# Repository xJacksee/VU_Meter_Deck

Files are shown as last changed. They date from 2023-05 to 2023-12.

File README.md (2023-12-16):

# VU_Meter_Deck
Retro audio level indicator with analog driver circuit.
\
The goal of this project is to create analog driver circuit for analog VU meter gauges. This device works with standard line level audio signals and is meant to be connected paralell to audio source and reciever (headphones or amplifier). VU Meter Deck is equipped with two sets of RCA and 1/4 inch audio jack connectors, where one set is meant to be conneced to audio source and the other to reciever as a pass-through configuration.

Front view

## Driver circuit

The driver circuit is fully analog made using TL084 quad op amps for processing (one per channel). It is meant to powered by an external 12V DC 200mA power supply. 

The circuit performs these functions:

- amplify input audio signal that arbitrarly selected value of 25mV RMS will be able to achieve 0dB on gauge's scale,
- rectify ampified signal by using op amp precision full-wave rectifier circuit,
- calculate the average of recified signal by using RC circuit,
- bufer the signal to analog gauges,
- provide input and output overvoltage protection.

View of inside circuit

## Measurments and characteristic of driver circuit

Output voltage level for 25mV RMS sinusoidal signal has been measured for different frequencies and plotted on graph below using MATLAB and Curve Fitter Toolbox. Gaussian aproximation was used to create aproximating function. For this plot, output for 1kHz sine was used as a reference value.

Driving circuit output voltage level dependace on input sine frequency

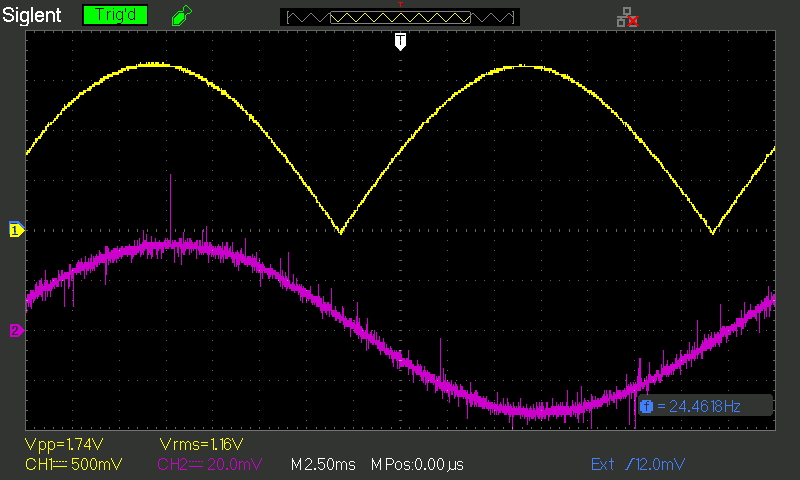
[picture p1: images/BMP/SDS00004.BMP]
Rectified 1kHz sinusoidal waveform


## Contributors
Szymon Bartosik

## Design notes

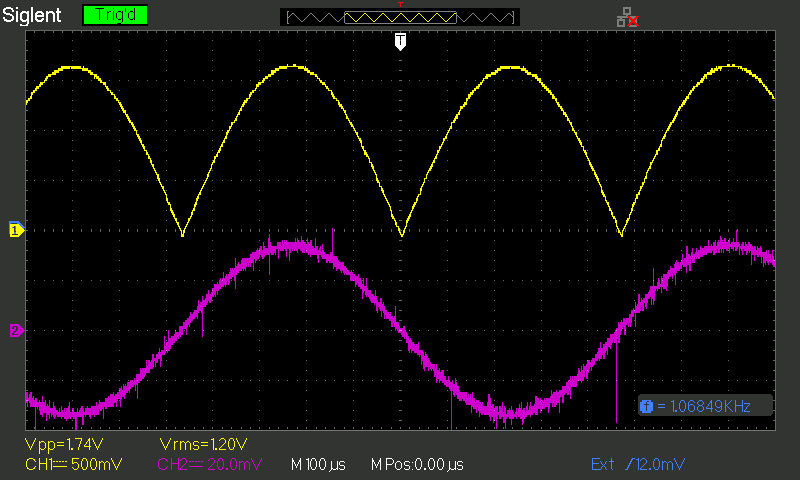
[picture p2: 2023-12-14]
images/BMP/SDS00001.BMP

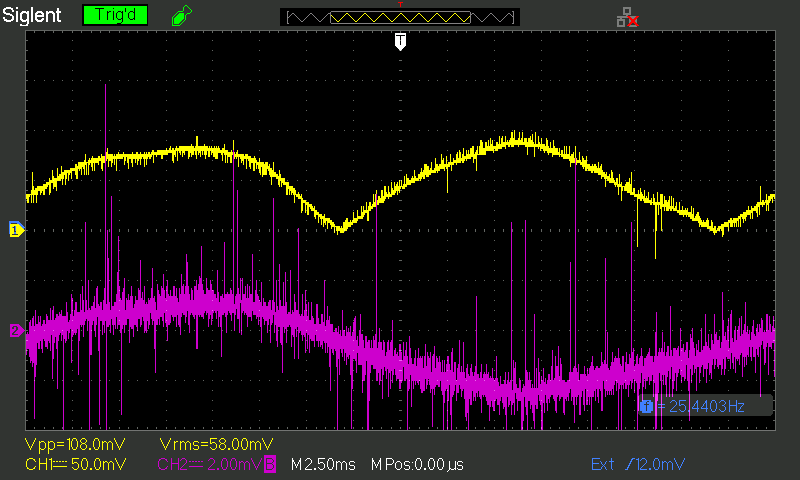
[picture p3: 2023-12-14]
images/BMP/SDS00005.BMP

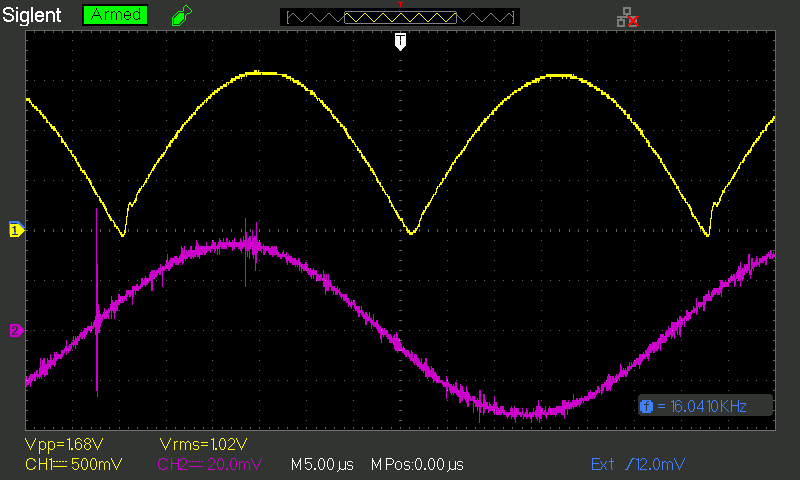
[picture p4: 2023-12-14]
images/BMP/SDS00002.BMP

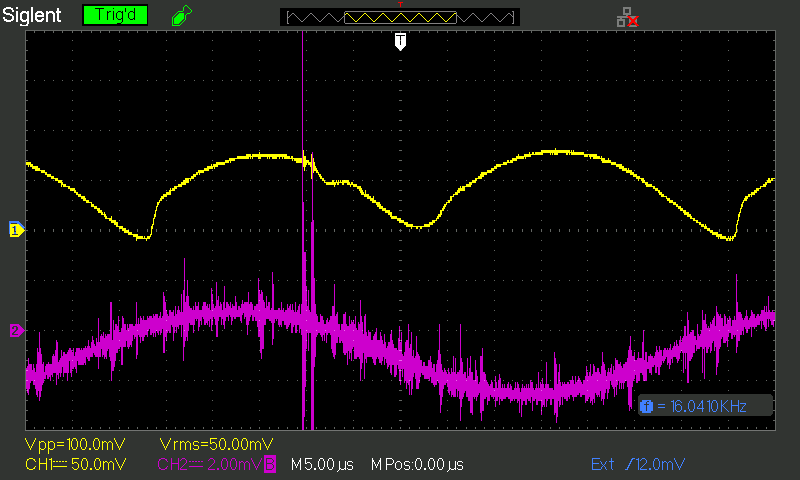
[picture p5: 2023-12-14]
images/BMP/SDS00003.BMP

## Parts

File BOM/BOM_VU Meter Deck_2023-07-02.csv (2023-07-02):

ID | Name | Designator | Footprint | Quantity | Manufacturer Part | Manufacturer | Supplier | Supplier Part
1 | 1u | C1,C4,C8,C9 | RAD-0.2 | 4 | CT40805Y105M500F3R | SR PASSIVES | TME | CCT-1U/50V
2 | 47p | C2,C5 | RAD-0.2 | 2 | CC-47/100 | SR PASSIVES | TME | CC-47/100
3 | 10u | C3,C6,C7,C10 | CAP-D5.0×F2.0 | 4 | SD1E106M05011BB | SAMWHA | TME | SD1E106M05011BB
4 | 1N4148 | D1,D4,D5,D8 | DO-35_BD2.0-L4.2-P8.20-D0.5-RD | 4 | 1N4148 | DIOTEC SEMICONDUCTOR | TME | 1N4148-DIO
5 | BAT48 | D2,D3,D6,D7 | DO-35_BD2.0-L4.2-P8.20-D0.5-RD | 4 | BAT48 | STMicroelectronics | TME | BAT48
6 | 1N4007 | D9 | DO-41_BD2.4-L4.7-P8.70-D0.9-RD | 1 | 1N4007 | DC COMPONENTS | TME | 1N4007-DC
7 | BZX55C4V3 | D10,D11,D12,D13 | DO-35_BD2.0-L4.0-P8.00-D0.5-FD | 4 | BZX55C4V3-TAP | VISHAY | TME | BZX55C4V3-TAP
8 | B3B-XH-A | J1,J3,J5 | CONN-TH_3P-P2.50_B3B-XH-A-BK-LF-SN | 3 | B3B-XH-A-BK(LF)(SN) | JST | TME | B3B-XH-A
9 | B2B-XH-A | J2,J4,J6,J7,J8 | CONN-TH_2P-P2.50_JST_B2B-XH-A-M | 5 | B2B-XH-A-M(LF)(SN)(P) | JST | TME | B2B-XH-A
10 | SCHURTER 4840.2200 | J9 |  | 1 | 4840.2200 | SCHURTER | TME | 4840.2200
11 | KEYSTONE 598 | J10,J12 |  | 2 | 598 | KEYSTONE | TME | KEYS598
12 | AMPHENOL ACJS-MVS-3 | J11,J14 |  | 2 | ACJS-MVS-3 | AMPHENOL | TME | ACJS-MVS-3
13 | KEYSTONE 580 | J13,J15 |  | 2 | 580 | KEYSTONE | TME | KEYS580
14 | AZ850-12 | K1 | AZ850 | 1 | AZ850-12 | ZETTLER | TME | AZ850-12
15 | XHP-2 | P1,P4,P6,P7,P8 |  | 5 | XHP-2 | JST | TME | XHP-2
16 | XHP-3 | P2,P3,P5 |  | 3 | XHP-3 | JST | TME | XHP-3
17 | 1k | R1,R2,R4,R7,R8,R9,R10,R12,R15,R16,R18,R20 | R_AXIAL-0.4 | 12 | CF1/4W-1K | SR PASSIVES | TME | CF1/4W-1K
18 | 47k | R3,R5,R11,R13 | R_AXIAL-0.4 | 4 | CF1/4W-47K | SR PASSIVES | TME | CF1/4W-47K
19 | 100k | R6,R14 | R_AXIAL-0.4 | 2 | CF1/4W-100K | SR PASSIVES | TME | CF1/4W-100K
20 | 10k | R17,R19,R21,R22 | R_AXIAL-0.4 | 4 | CF1/4W-10K | SR PASSIVES | TME | CF1/4W-10K
21 | 10k | RP1,RP2,RP3,RP4 | RES-ADJ-TH_3296W | 4 | T910W-10K | SR PASSIVES | TME | T910W-10K
22 | B100k | RP5,RP6 |  | 2 | R16148-1A-1-B100K | SR PASSIVES | TME | R16148-1A-1-B100K
23 | Marquardt 1801.6115 | S1 |  | 1 | 1801.6115 | Marquardt | TME | 1801.6115
24 | SD-39 | VU1,VU2 |  | 2 | SD-39
25 | TL084BCN | U1,U2 | PDIP-14 | 2 | TL084BCN | Texas Instruments | TME | TL084BCN
26 | LM358P | U3 | PDIP-8_L9.6-W6.4-P2.54-LS7.6-BL | 1 | LM358P | Texas Instruments | TME | LM358P

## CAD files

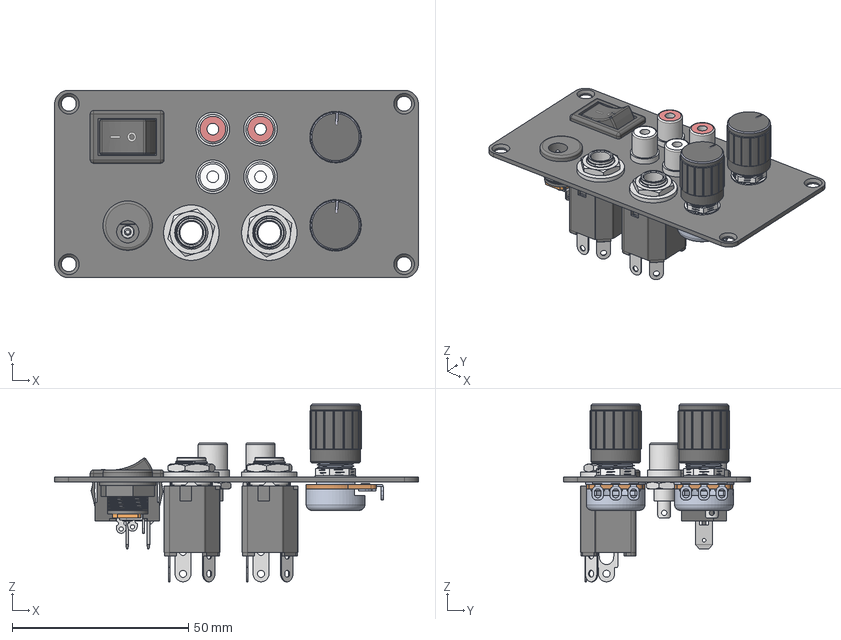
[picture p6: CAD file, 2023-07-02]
models/back_panel_assembly.stp
103.1 x 53.1 x 50.3 mm
back_panel
Housing
Rocker
Terminal x 2
RCA cinch RS 411-081_3 x 4
RCA cinch RS 411-081_0_w x 2
RCA cinch RS 411-081 x 4
RCA cinch RS 411-081_0_r x 2
RCA cinch RS 411-081_2 x 4
4840.2200-03_nut
ACJS-LNS-2S x 2
NUT x 2
Washer 2 x 2
Single_Pot x 2
Single_Pot_0 x 2
Single_Pot_1 x 2
Single_Pot_2 x 2
Single_Pot_3 x 6
Single_Pot_4 x 6
Single_Pot_5 x 2
Pot_washer x 2
Pot_nut x 2
Potentiometer knob_A15x17-PK-AB-K-I x 2

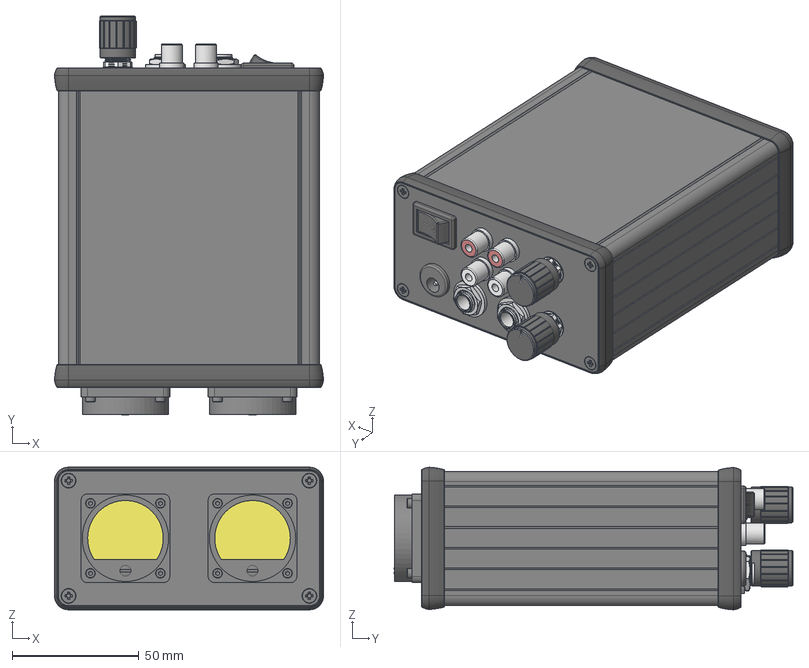
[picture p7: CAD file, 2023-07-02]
models/vu_meter_deck_assembly.stp
106.1 x 157.4 x 56.3 mm
1455N Extrusion
1455N Cover
1455 screw x 8
N1 Bezel Closed x 2
front_panel
SD-39_VU_gauge x 2
din_912-m2x0_4-10-10_9 x 8
nut_din934_m2-10 x 8
back_panel
Housing
Rocker
Terminal x 2
RCA cinch RS 411-081_3 x 4
RCA cinch RS 411-081_0_w x 2
RCA cinch RS 411-081 x 4
RCA cinch RS 411-081_0_r x 2
RCA cinch RS 411-081_2 x 4
4840.2200-03_nut
ACJS-LNS-2S x 2
NUT x 2
Washer 2 x 2
Single_Pot x 2
Single_Pot_0 x 2
Single_Pot_1 x 2
Single_Pot_2 x 2
Single_Pot_3 x 6
Single_Pot_4 x 6
Single_Pot_5 x 2
Pot_washer x 2
Pot_nut x 2
Potentiometer knob_A15x17-PK-AB-K-I x 2
board_plain

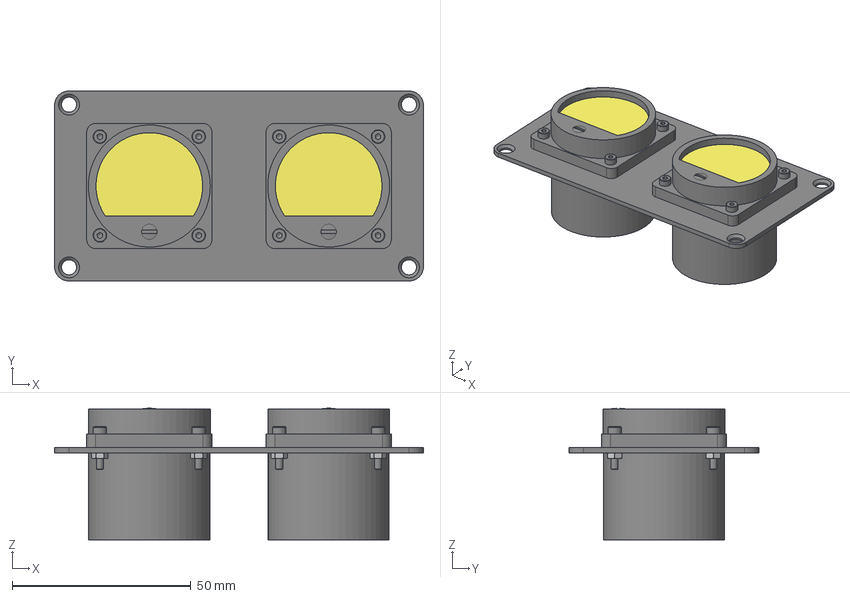
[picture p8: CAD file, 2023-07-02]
models/front_panel_assembly.stp
103.1 x 53.1 x 36.8 mm
front_panel
SD-39_VU_gauge x 2
din_912-m2x0_4-10-10_9 x 8
nut_din934_m2-10 x 8

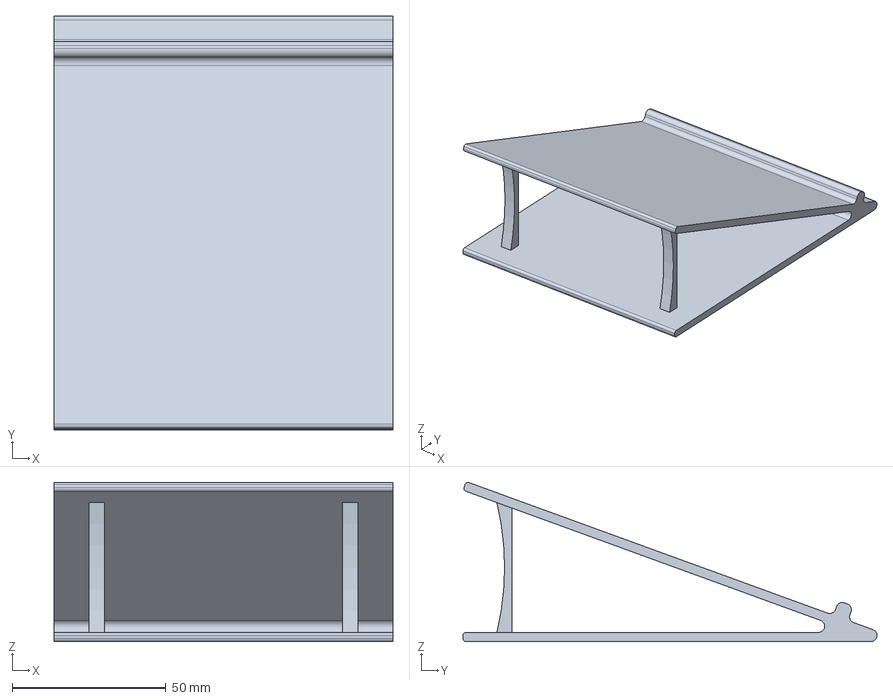
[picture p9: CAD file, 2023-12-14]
models/accessories/VU_Meter_Deck_Stand.stp
110.0 x 134.5 x 51.7 mm

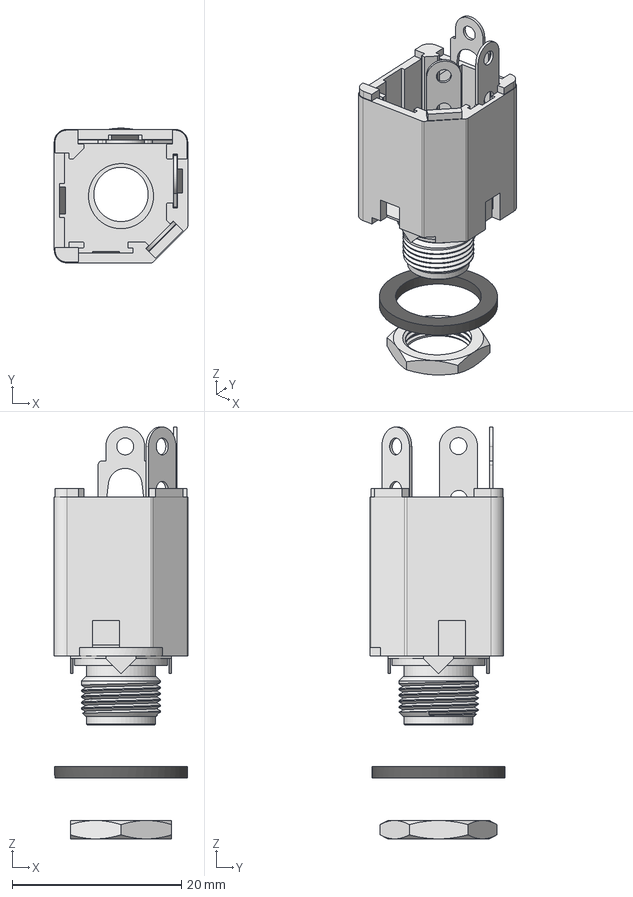
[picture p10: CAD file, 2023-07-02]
models/connectors/audio_jack/ACJS-MVS-3.stp
15.8 x 15.9 x 48.7 mm
ACJS-LNS-2S
Washer 2
NUT

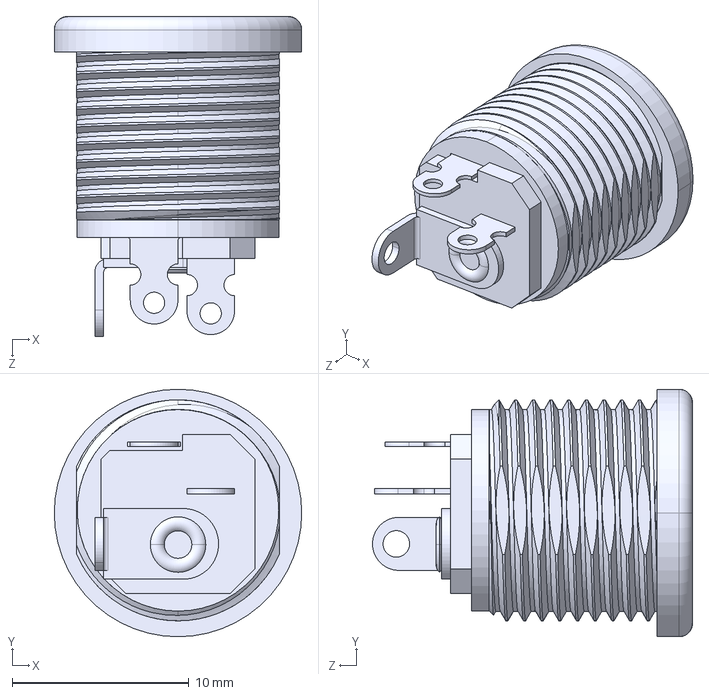
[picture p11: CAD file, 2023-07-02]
models/connectors/dc_jack/4840.2200-03.STEP
14.0 x 14.0 x 18.1 mm

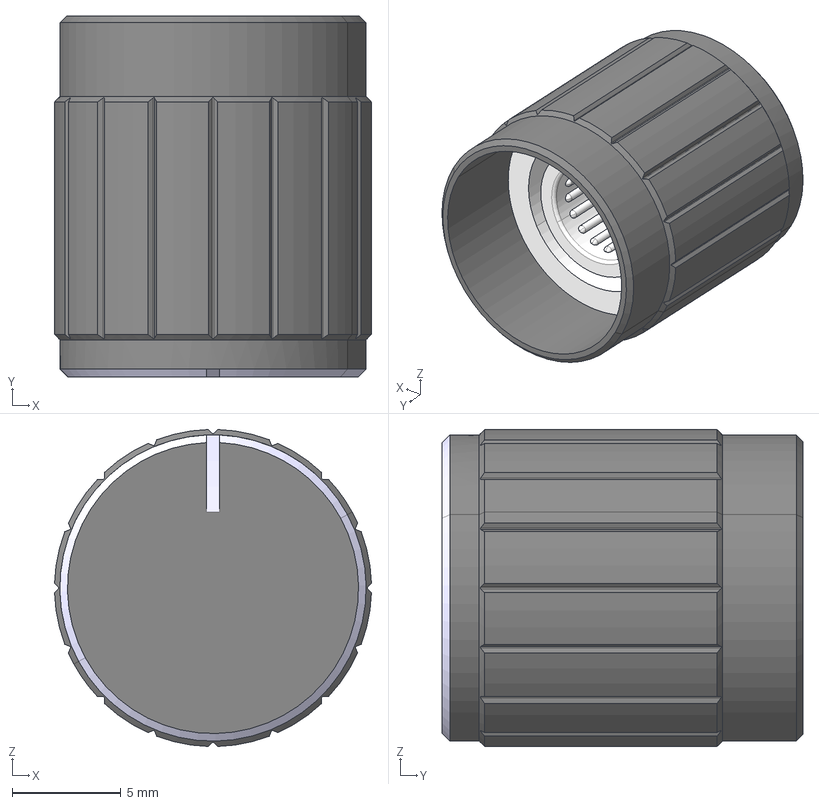
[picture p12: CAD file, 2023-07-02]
models/knob/Potentiometer knob_A15x17-PK-AB-K-I.stp
14.6 x 16.6 x 14.6 mm

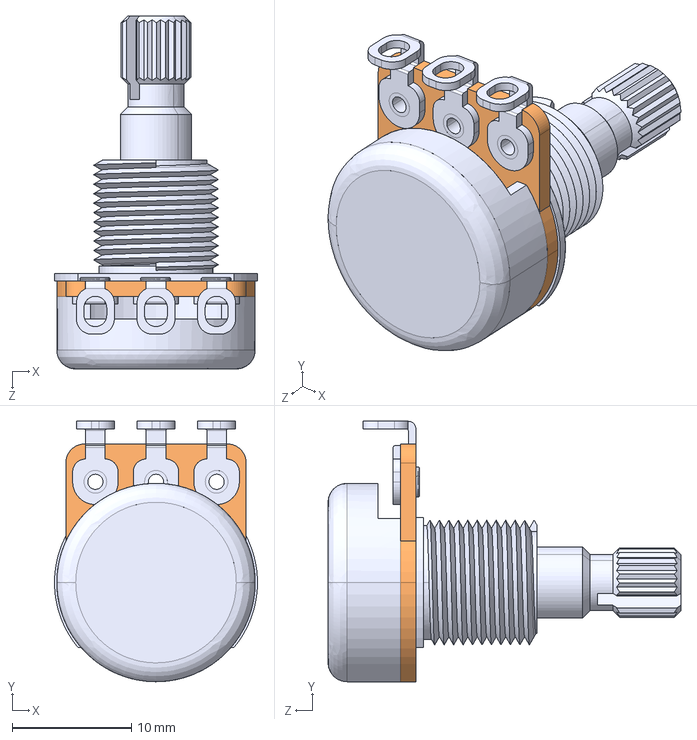
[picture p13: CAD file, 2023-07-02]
models/potentiometer/Single_Pot.IGS
17.0 x 21.8 x 29.6 mm

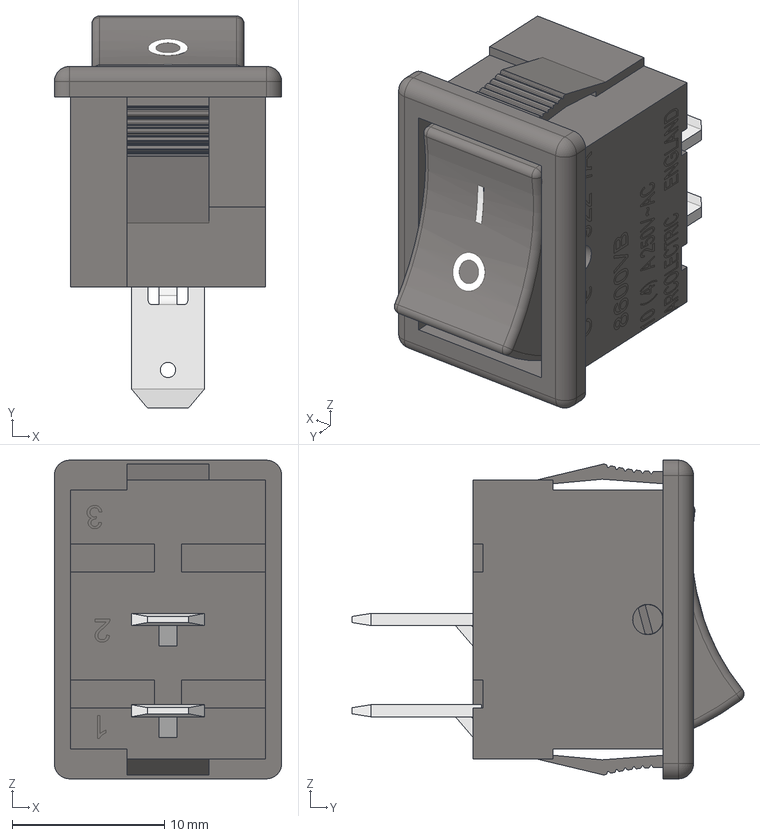
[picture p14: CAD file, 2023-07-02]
models/switch/ARCOLECTRIC_H8600VB.stp
14.9 x 25.8 x 20.9 mm
Housing
Rocker
Terminal x 2

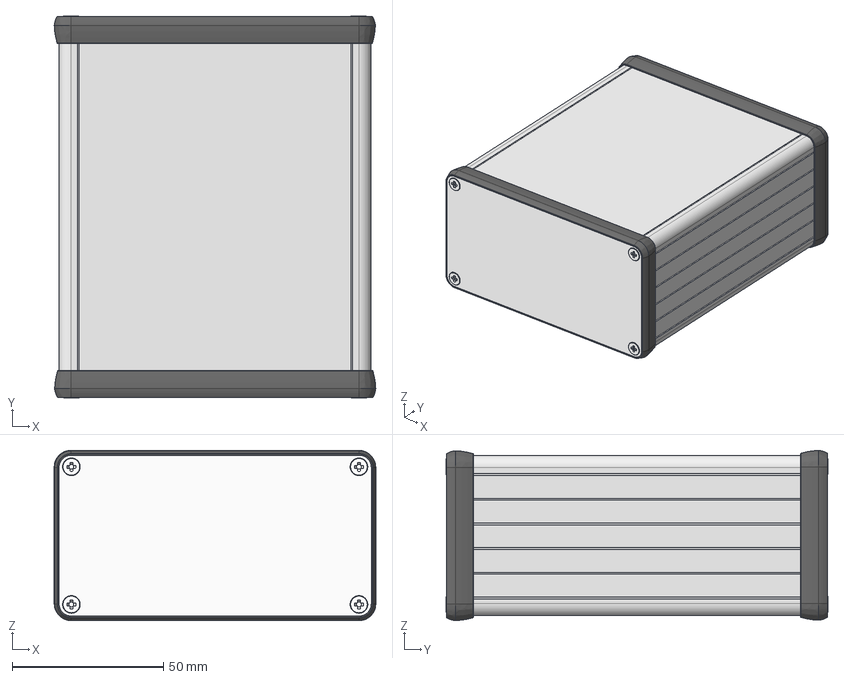
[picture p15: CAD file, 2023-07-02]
models/case/1455N1201.stp
106.3 x 126.2 x 56.3 mm
1455N Extrusion
1455N Cover
N1 Bezel Closed x 2
1455N End Plate x 2
1455 screw x 8

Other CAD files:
models/accessories/VU_Meter_Deck_Stand.stl
models/connectors/RCA/RCA cinch RS 411-081.x_t

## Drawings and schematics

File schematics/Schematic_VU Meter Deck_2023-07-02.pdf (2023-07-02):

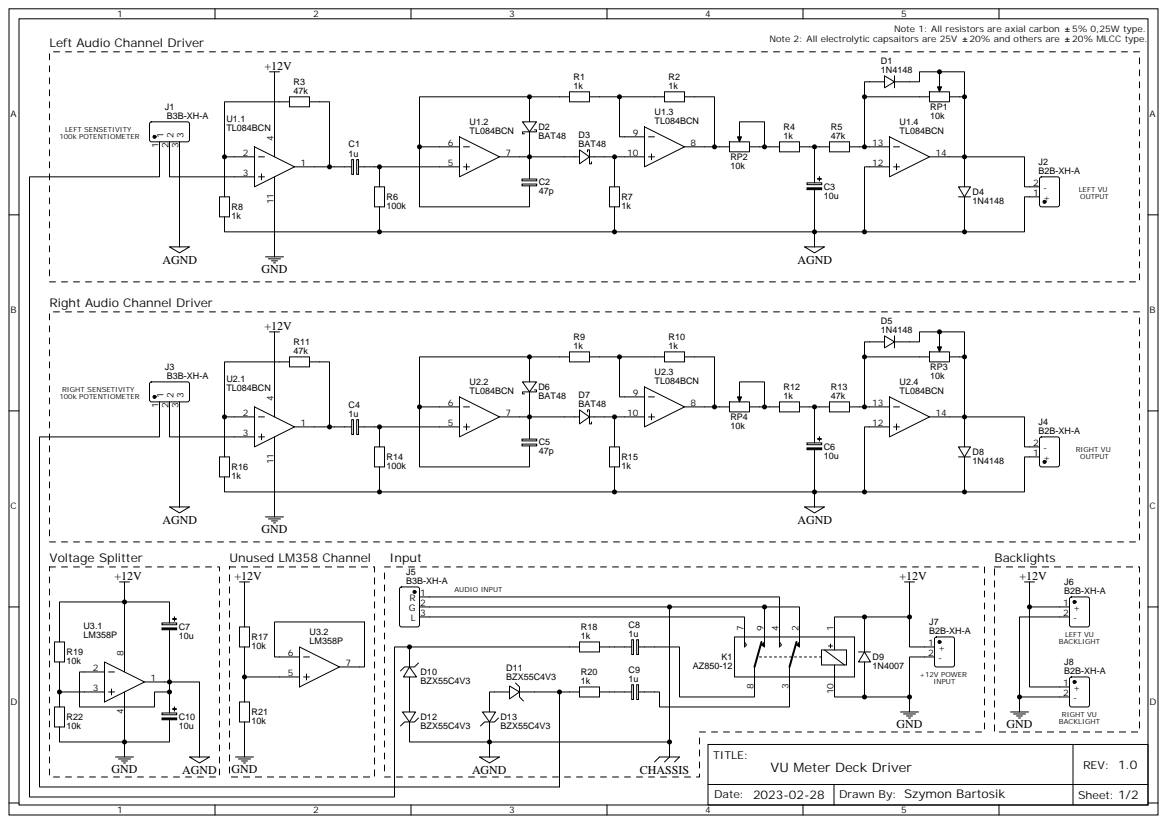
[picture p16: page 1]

Note 1: All resistors are axial carbon 5% 0,25W type.

Note 2: All electrolytic capsaitors are 25V 20% and others are 20% MLCC type.

Left Audio Channel Driver

Right Audio Channel Driver

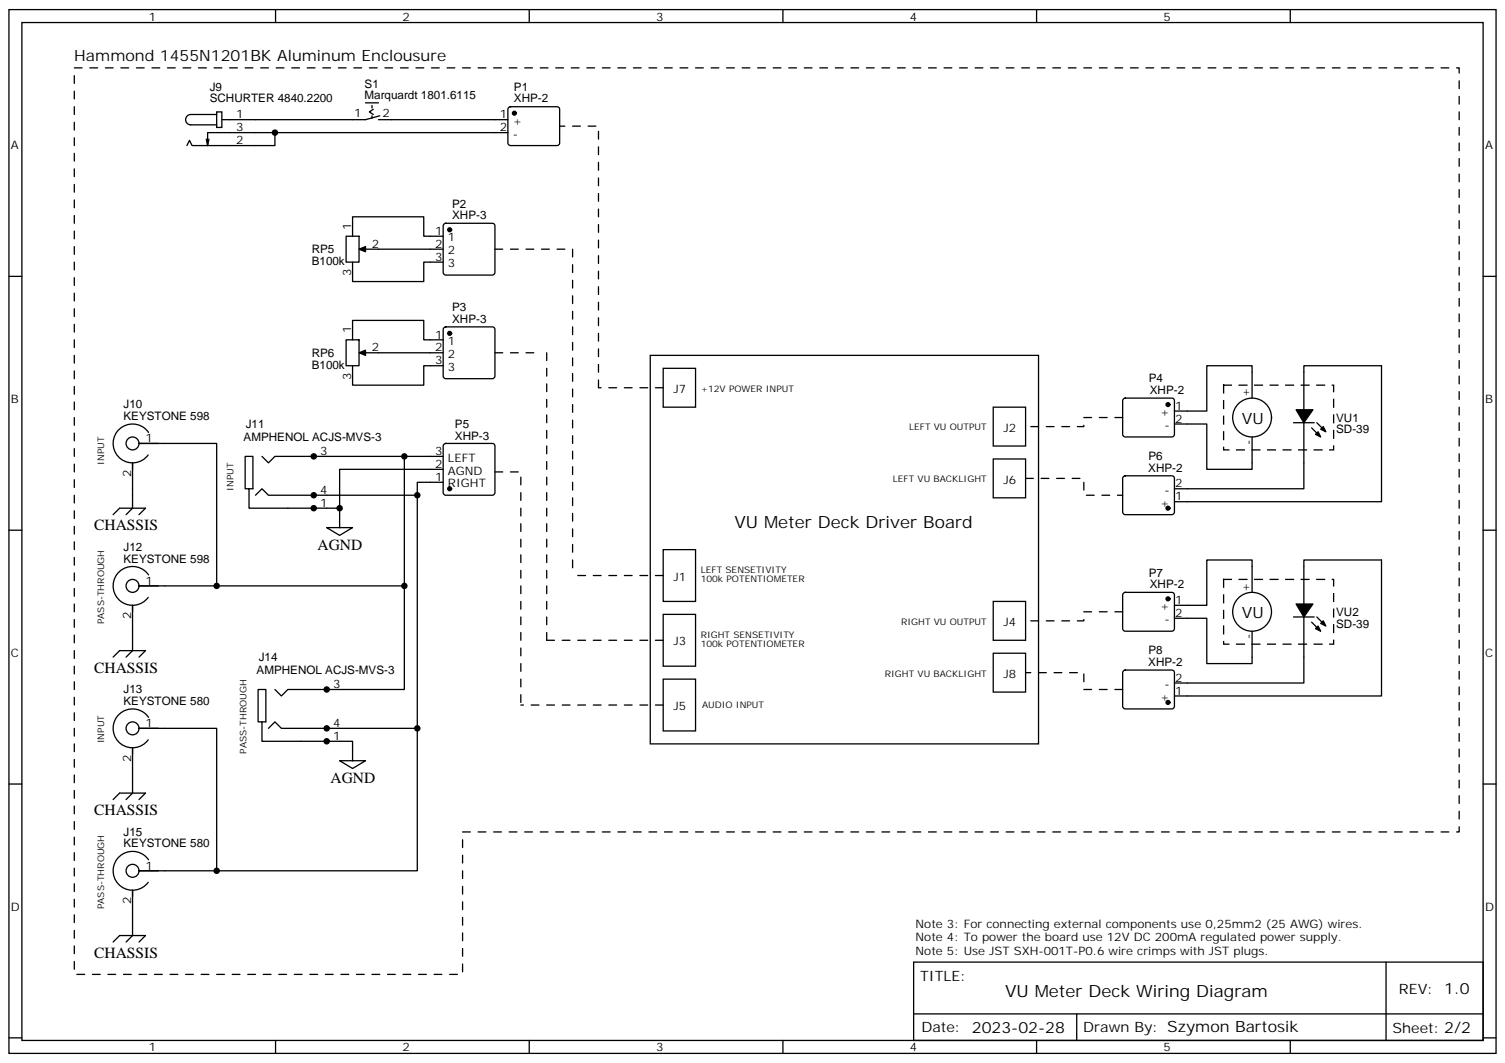
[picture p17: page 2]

INPUT INPUT PASS-THROUGH PASS-THROUGH

VU Meter Deck Driver Board

Note 3: For connecting external components use 0,25mm2 (25 AWG) wires.
Note 4: To power the board use 12V DC 200mA regulated power supply.
Note 5: Use JST SXH-001T-P0.6 wire crimps with JST plugs.
TITLE:

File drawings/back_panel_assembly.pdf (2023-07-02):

5
4

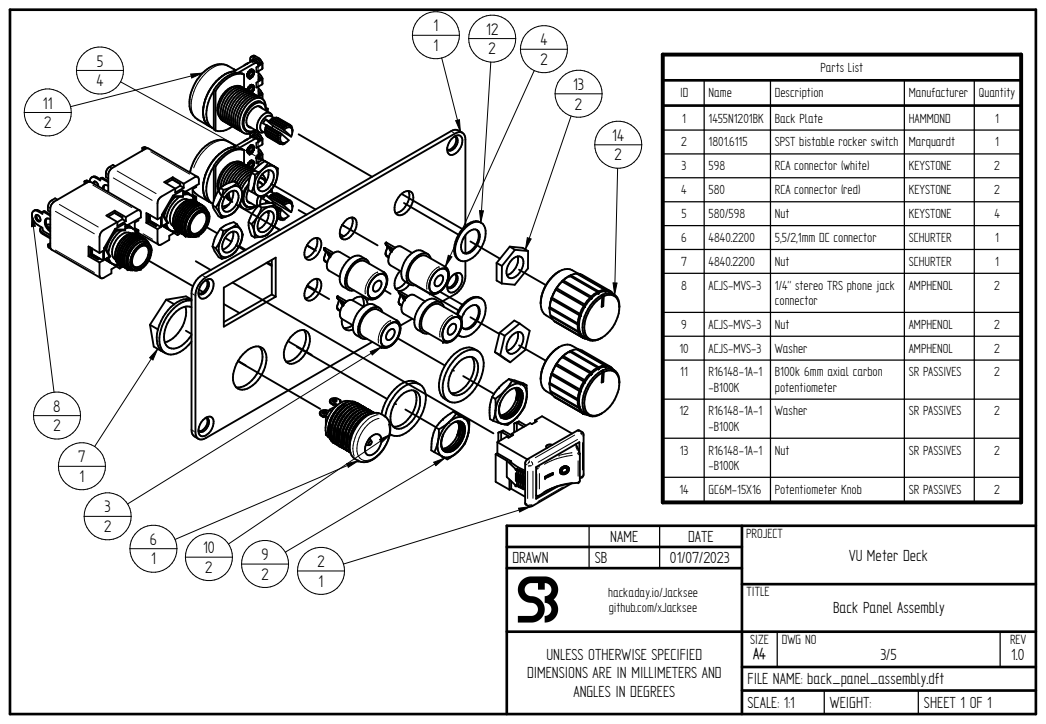
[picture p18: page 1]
TITLE; SIZE A4; DWG NO; REV 1.0; FILE NAME: back_panel_assembly.dft; SCALE: 1:1; WEIGHT:; SHEET 1 OF 1; Parts List; Name; Description; Manufacturer Quantity; 1455N1201BK Back Plate; HAMMOND; SPST bistable rocker switch Marquardt; RCA connector (white); KEYSTONE; RCA connector (red); Nut; 5,5/2,1mm DC connector; SCHURTER; ACJS-MVS-3 1/4" stereo TRS phone jack; connector; AMPHENOL; ACJS-MVS-3 Nut; ACJS-MVS-3 Washer; B100k 6mm axial carbon potentiometer; SR PASSIVES; Washer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

NAME | DATE | PROJECT VU Meter Deck

DRAWN | SB | 01/07/2023

hackaday.io/Jacksee
github.com/xJacksee

Back Panel Assembly

UNLESS OTHERWISE SPECIFIED
DIMENSIONS ARE IN MILLIMETERS AND
ANGLES IN DEGREES

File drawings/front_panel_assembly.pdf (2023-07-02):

4
8

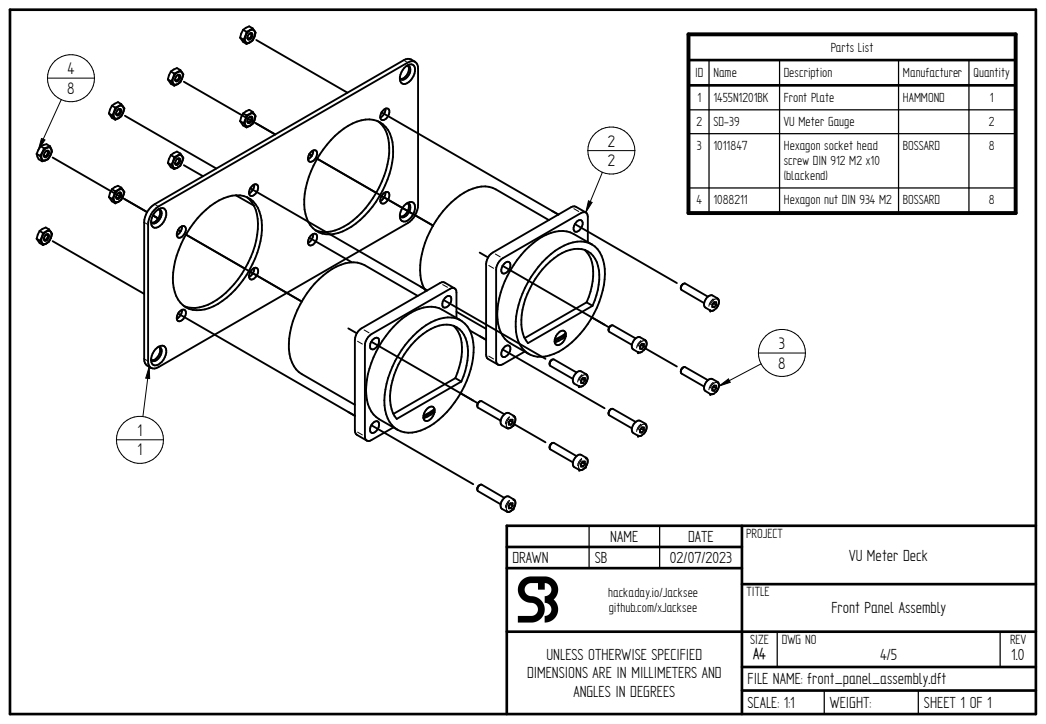
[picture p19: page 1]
TITLE; SIZE A4; DWG NO; REV 1.0; FILE NAME: front_panel_assembly.dft; SCALE: 1:1; WEIGHT:; SHEET 1 OF 1; Parts List

ID | Name | Description | Manufacturer | Quantity
1 | 1455N1201BK | Front Plate | HAMMOND | 1
2 | SD-39 | VU Meter Gauge | | 2
3 | 1011847 | Hexagon socket head screw DIN 912 M2 x10 (blackend) | BOSSARD | 8

4 | 1088211 | Hexagon nut DIN 934 M2 | BOSSARD | 8

NAME | DATE | PROJECT VU Meter Deck

DRAWN | SB | 02/07/2023

hackaday.io/Jacksee
github.com/xJacksee

Front Panel Assembly

UNLESS OTHERWISE SPECIFIED
DIMENSIONS ARE IN MILLIMETERS AND
ANGLES IN DEGREES

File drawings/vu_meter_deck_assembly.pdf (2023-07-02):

7
1

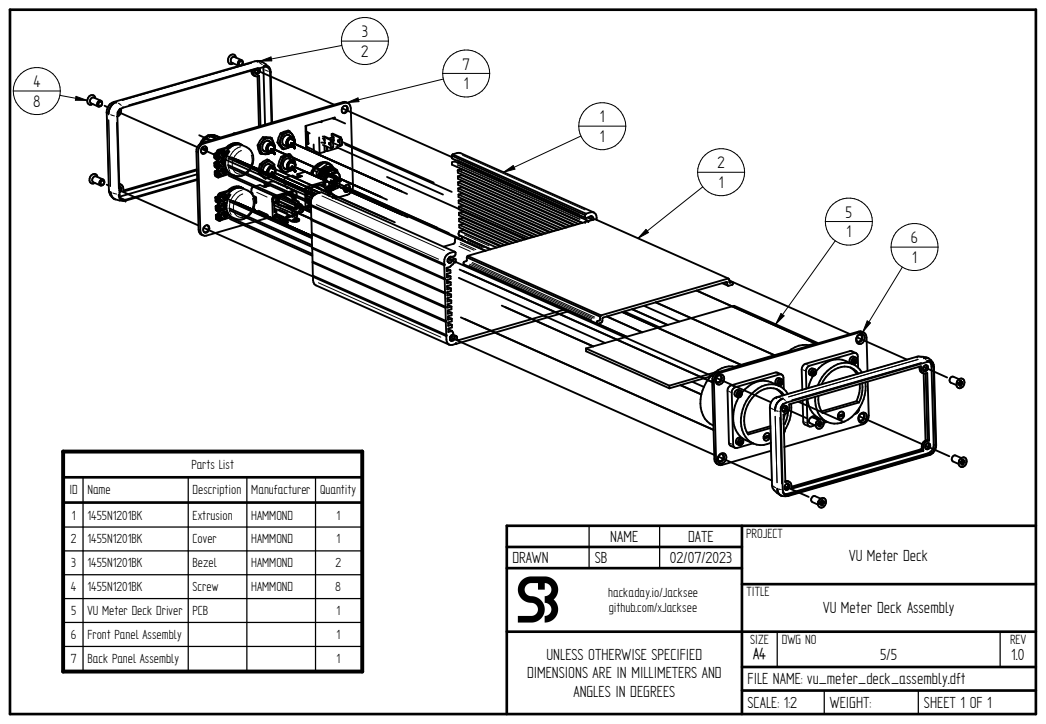
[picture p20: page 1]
NAME; DATE; TITLE; SCALE: 1:2; WEIGHT:; SHEET 1 OF 1; PROJECT; Parts List; Cover; HAMMOND

ID | Name | Description | Manufacturer | Quantity
1 | 1455N1201BK | Extrusion | HAMMOND | 1

DRAWN | SB | 02/07/2023

VU Meter Deck

3 | 1455N1201BK | Bezel | HAMMOND | 2
4 | 1455N1201BK | Screw | HAMMOND | 8
5 | VU Meter Deck Driver | PCB | | 1
6 | Front Panel Assembly | | | 1
7 | Back Panel Assembly | | | 1

hackaday.io/Jacksee
github.com/xJacksee

VU Meter Deck Assembly

UNLESS OTHERWISE SPECIFIED DIMENSIONS ARE IN MILLIMETERS AND ANGLES IN DEGREES | SIZE A4 | DWG NO 5/5 | REV 1.0

FILE NAME: vu_meter_deck_assembly.dft

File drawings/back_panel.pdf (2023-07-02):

10,85 19,8

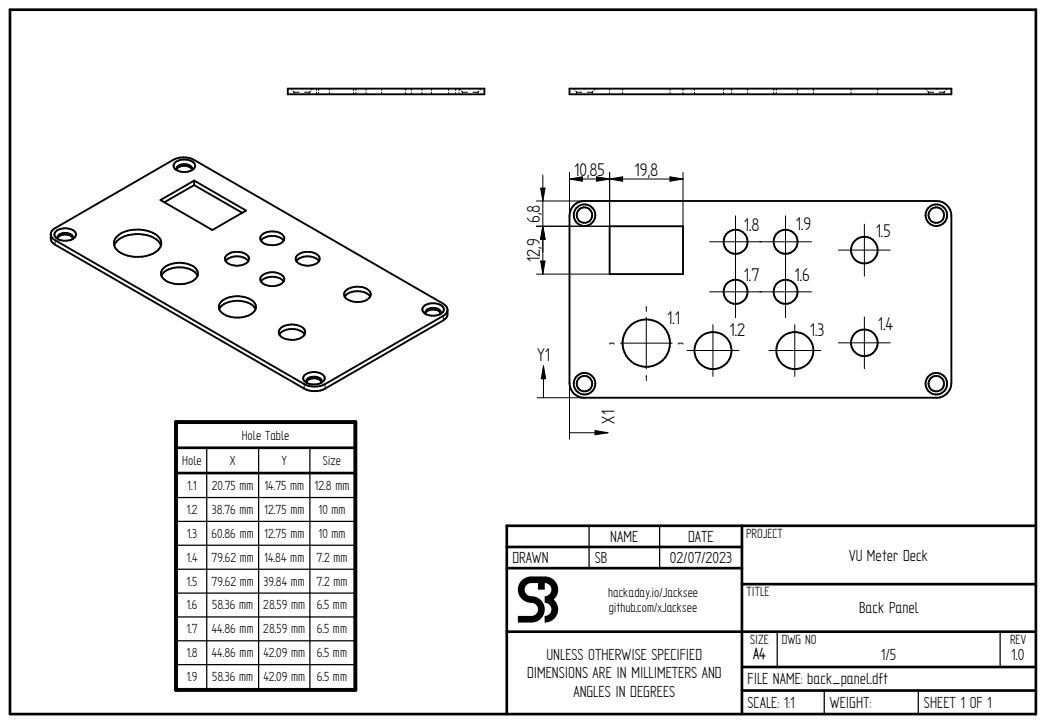
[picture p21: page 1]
DRAWN; TITLE; Back Panel; SCALE: 1:1; WEIGHT:; SHEET 1 OF 1; Hole Table

Hole | X | Y | Size
1.1 | 20.75 mm | 14.75 mm | 12.8 mm
1.2 | 38.76 mm | 12.75 mm | 10 mm
1.3 | 60.86 mm | 12.75 mm | 10 mm

NAME | DATE | PROJECT VU Meter Deck

hackaday.io/Jacksee
github.com/xJacksee

1.6 | 58.36 mm | 28.59 mm | 6.5 mm
1.7 | 44.86 mm | 28.59 mm | 6.5 mm
1.8 | 44.86 mm | 42.09 mm | 6.5 mm

UNLESS OTHERWISE SPECIFIED DIMENSIONS ARE IN MILLIMETERS AND ANGLES IN DEGREES | SIZE A4 | DWG NO 1/5 | REV 1.0

FILE NAME: back_panel.dft

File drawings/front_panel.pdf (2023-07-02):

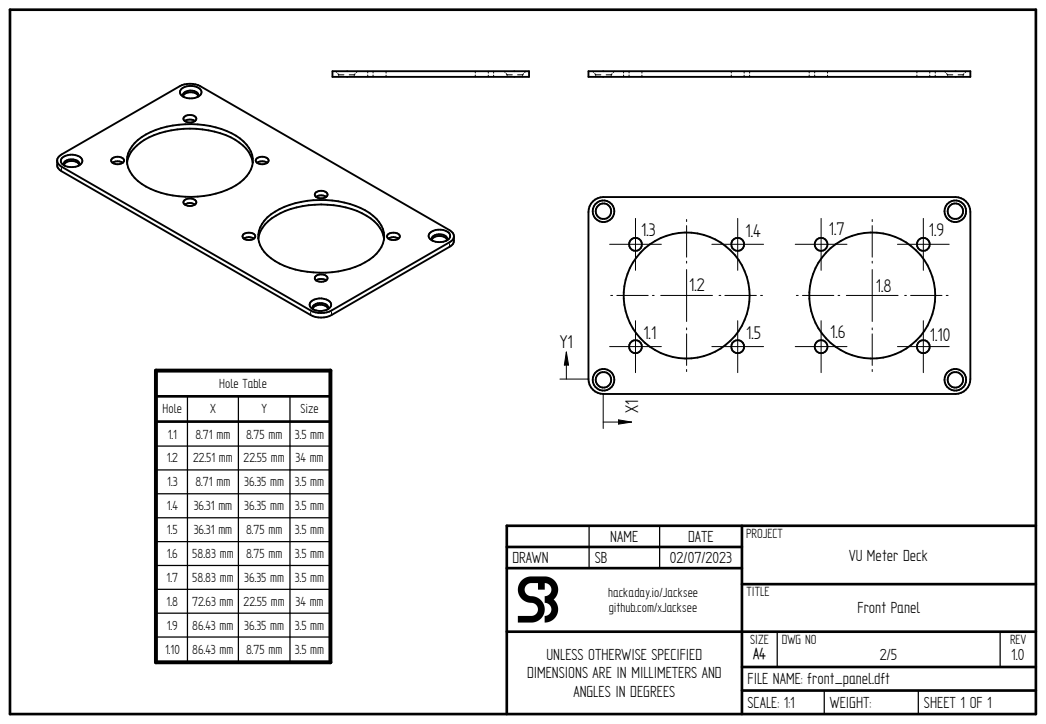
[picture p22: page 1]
TITLE; Front Panel; SIZE A4; DWG NO; REV 1.0; FILE NAME: front_panel.dft; SCALE: 1:1; WEIGHT:; SHEET 1 OF 1; Hole Table

Hole | X | Y | Size
1.1 | 8.71 mm | 8.75 mm | 3.5 mm
1.2 | 22.51 mm | 22.55 mm | 34 mm
1.3 | 8.71 mm | 36.35 mm | 3.5 mm
1.4 | 36.31 mm | 36.35 mm | 3.5 mm
1.5 | 36.31 mm | 8.75 mm | 3.5 mm
1.6 | 58.83 mm | 8.75 mm | 3.5 mm

NAME | DATE | PROJECT VU Meter Deck

DRAWN | SB | 02/07/2023

1.8 | 72.63 mm | 22.55 mm | 34 mm
1.9 | 86.43 mm | 36.35 mm | 3.5 mm
1.10 | 86.43 mm | 8.75 mm | 3.5 mm

hackaday.io/Jacksee
github.com/xJacksee

UNLESS OTHERWISE SPECIFIED
DIMENSIONS ARE IN MILLIMETERS AND
ANGLES IN DEGREES

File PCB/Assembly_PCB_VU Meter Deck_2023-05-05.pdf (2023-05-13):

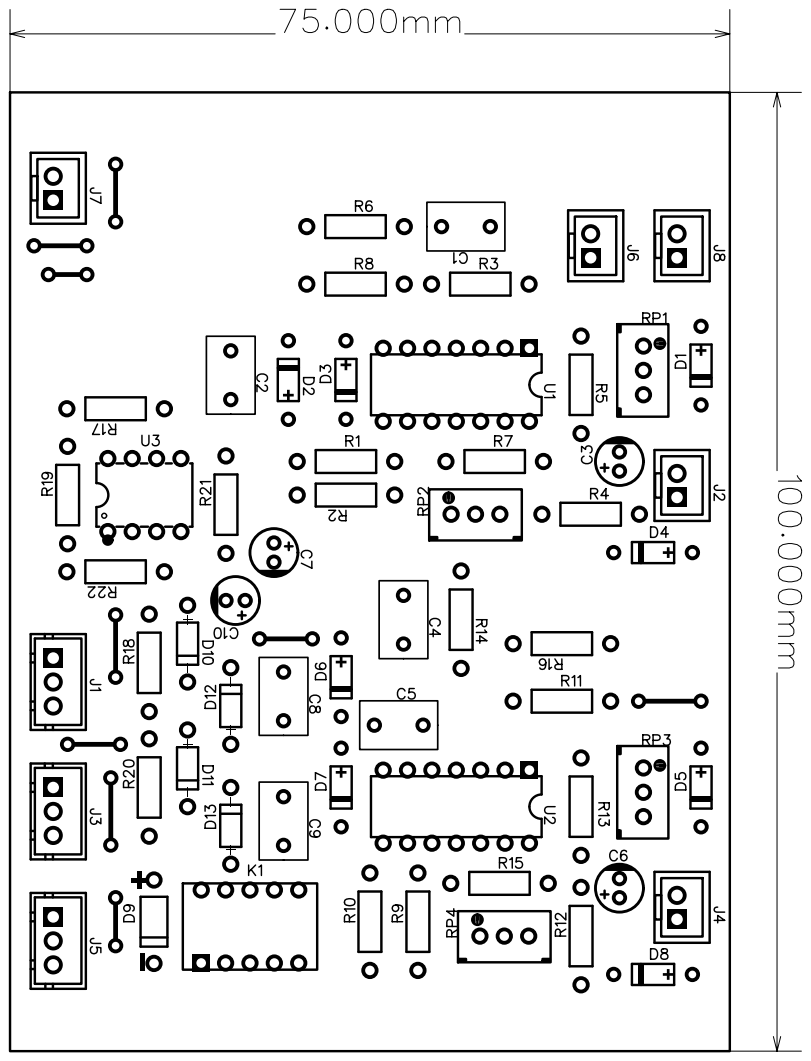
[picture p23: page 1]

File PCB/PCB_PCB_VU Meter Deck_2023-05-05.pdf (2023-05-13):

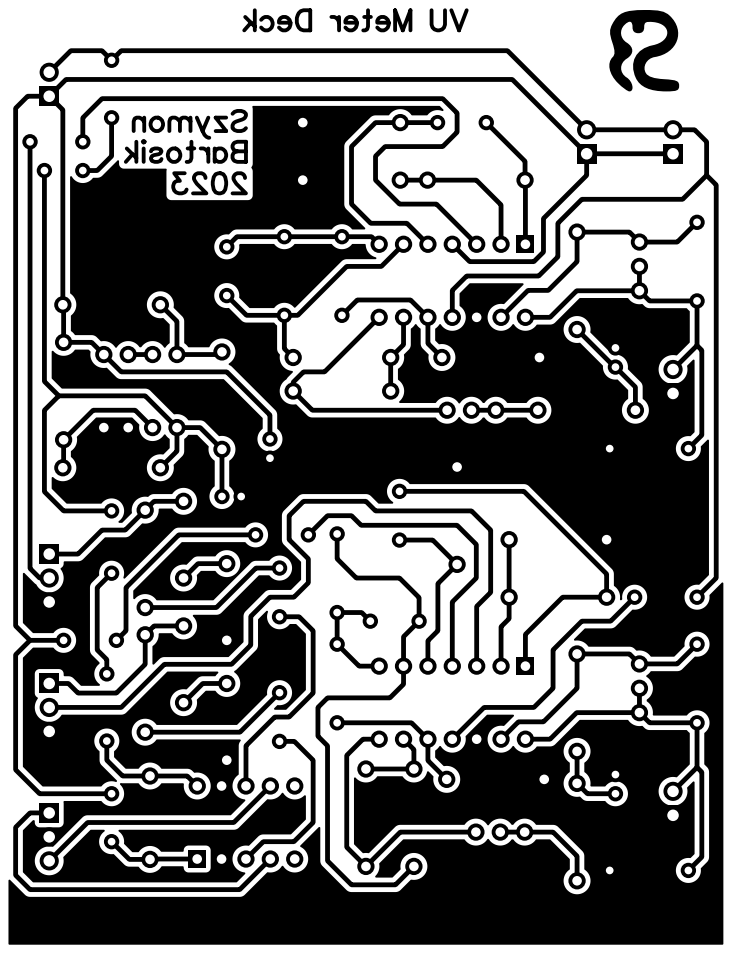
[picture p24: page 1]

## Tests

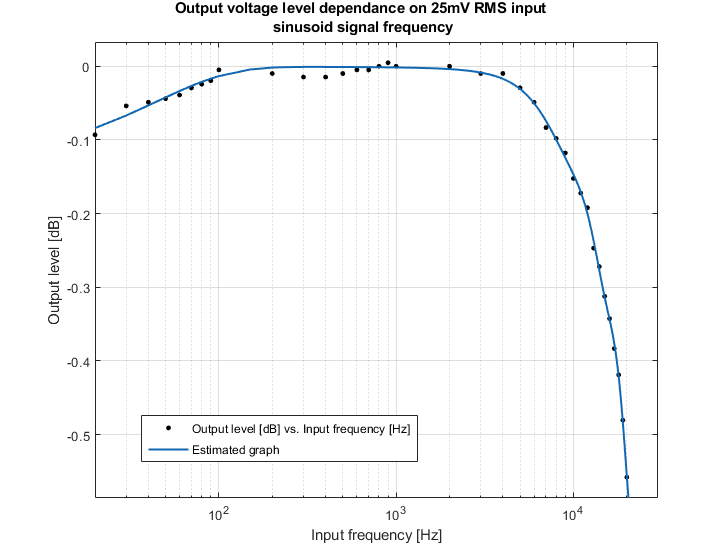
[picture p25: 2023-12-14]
measurements/output_vs_freq.png

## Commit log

2023-07-02 Fixed BOM file
    [BOM_VU Meter Deck_2023-07-02.csv]
2023-07-02 Deleted old BOM file
    [BOM_VU Meter Deck_2023-05-05.csv]
2023-07-02 Fixed schematics
2023-12-14 images+measurements+stand models
    [VU_Meter_Deck_Stand.stl, VU_Meter_Deck_Stand.stp]
